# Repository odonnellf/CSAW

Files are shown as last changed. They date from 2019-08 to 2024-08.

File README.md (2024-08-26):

# CSAW
## (C)ontrol (S)urface using (A)rduino & (W)ireless capabilities

***This project is presented as part of the thesis requirements for the MSc. in Music & Technology, awarded by Cork School of Music.***

Audio control surfaces are practical tools for editing and mixing in a digital audio workstation. Despite recent technological advancements, however, there is a lack of robust physical commercial controllers with seamless wireless functionality.

This project repository consists of relevant files for the design and implementation of CSAW – an audio Control Surface built using the Arduino platform and Wireless capabilities. CSAW aims to remedy limitations of mobile control applications and certain hardware controllers through devising a proof of concept control surface and software platform using sophisticated open-source applications and wireless communication protocols.

## Software, Drivers & Libraries
(Installations covered in notes below)
* Arduino IDE
* Arduino Mega driver 
* ESP8266 board and library for Arduino IDE
* Purr Data - Pure Data distribution
* CNMAT/OSC Arduino library
* Arduino_Pd Pd abstraction library

## Repository Structure
/
* daw-files/	: DAW config files and templates for CSAW
* design/		: design diagrams and other documents
* documents/	: main thesis submission documents
* examples/	: example Arduino sketches and Pd patches, referenced in documentation
* main/		: main CSAW prototype Arduino sketches and Pd patches

## Install Notes
A Quick Start Guide accompanies this README with details on getting the controller working instantly (QuickStart.pdf). The steps below outline the process to replicate development, install requirements to enable code expansion on the controller and how to change the prototype build.

### I. Arduino:
	1. Download the Arduino IDE and install: https://www.arduino.cc/en/main/software .
	2. Connect CSAW's Arduino component via USB. Ensure that the correct board is selected in the IDE: Tools->Board->Arduino/Genuino Mega or Mega 2560
	3. Check that the correct port is selected under: Tools->Port. If this is greyed out, check that the Arduino is fully plugged in. If it is then there may be a driver issue, as Arduino Mega is known to have certain issues, particularly with Windows 10. Follow Arduino's documentation how to resolve this: https://www.arduino.cc/en/Guide/DriverInstallation 
	4. Prototype sketches and other code can now be uploaded to Arduino.

### II. ESP8266 (WiFi chip) board & library:
	1. To add the ESP8266 board manager and library, first go to: File->Preferences in the IDE.
	2. Paste the following link into the "Additional Boards Manager URLs" field and click OK: http://arduino.esp8266.com/stable/package_esp8266com_index.json
	3. Go to Tools->Board->Board Manager and search for 'ESP8266'. Select 'Install' and restart the IDE once it finishes.
	4. Sketches can now be uploaded to ESP8266 modules. Connect the module/device via USB.
	5. Select the appropriate board in the Tools->Board menu (for ESP-01 this is just 'Generic ESP8266 Module) and select the COM port.
	6. The library includes some examples to test the module works - e.g. Blink, etc.

### III. Open Sound Control library:
	1. Navigate to the main OSC GitHub repo for Arduino developed by CNMAT and download as a zip file: https://github.com/CNMAT/OSC .
	2. In the Arduino IDE, go to: Sketch->Include Library->Add .ZIP Library . Select the OSC zip and click OK.
	3. Once it finishes installing, restart the IDE. Under File->Examples, there should now be some extra examples under the OSC umbrella in the 'Examples from Custom Libraries' section.

### IV. Purr Data and abstractions
	1. CSAW uses the 'Purr Data' distribution of Pure Data. Download and install it from the GitHub repo at the following link: https://github.com/agraef/purr-data/releases .
	2. Download the 'Arduino_Pd' abstraction library: https://github.com/alexdrymonitis/Arduino_Pd .
	3. CSAW's Prototype A patch and examples use this library's 'serial_print.pd' patch for correctly reading values printed to Serial from Arduino. Copy this file into any directory with CSAW Pd code.

### V. CSAW:
	1. Download this project repository. Refer to the folder structure above for further details.
	2. Arduino and ESP sketches can now be easily uploaded via USB.
	3. Run the appropriate Prototype patch. For PrototypeA, select the USB COM port Arduino is connected to. For PrototypeB, wait for ESP to connect to Pd.
	4. Ensure that the patch is responding to controller actions.

### VI. DAW:
	(***For wireless/PrototypeB, connect to the network defined by the ESP8266 sketch and ensure the PC has the defined IP address.***)
	1. Open a supported DAW and import the config file. Alternatively, open the DAW template.
	2. This will contain all tracks, plugins/FX, OSC control surface etc. Double-check that the port matches the settings in the Prototype Pd patch. Import the REAPER key mapping file from the Action List menu.
	3. Check once more that actions are being mapped in the Prototype patch and then click the DAW connect button.

## System Requirements
- This system was developed and tested on a Dell Inspiron laptop with the following specifications:
	* Intel Core i7-8565U CPU @ 1.80GHz 1.99 GHz
	* 16.0GB installed memory (RAM)
	* Windows 10 Pro Operating System

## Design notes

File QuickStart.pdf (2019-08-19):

## CSAW Quick Start Guide

### Prototype B (Wireless) / DEFAULT

- CSAW is configured to send controller messages via its ESP8266 WiFi module over a LAN using the TP_Link router. To use another network/IP, refer to the documentation, as the PrototypeB_ESP.ino file will need to be updated with the new WiFi config & IP and then flashed to the chip.
1. Turn on the accompanying TP_Link Router and connect to it using the PC that will be running the
Pd software and DAW. | SSID: CSAW_router | Password: c5@w_123!
2. The router should automatically assign IP address 192.168.1.100 to the PC. If not, then login to the device with these credentials and assign it, as ESP is configured to forward messages to this IP.

Address: http://tplinkwifi.net/ Password: c5@w_123!

3. Power on CSAW’s Arduino component using the 12V power supply. It can also be powered using the battery pack or via USB (though the latter may be redundant for wireless comm).
4. Download Purr Data and install: https://github.com/agraef/purr-data/releases . Run ‘PrototypeB.pd’ and wait for the connection.
5. Patch faders/knobs may start moving sporadically on startup. These can be calibrated quickly by simply moving each knob/fader on the desk. It’s advised to do this before operating with the DAW.

IMPORTANT: On first startup, messages will stop coming in to Pure Data from ESP after about a minute. This occurs due to the high number of messages being sent from ESP as pot voltages change rapidly – assumed to occur due to built-up potential energy from the last time the controller was plugged out. Wait for the PrototypeB patch to start reacting to actions again and continuously move/calibrate pots, even when it comes back up. Be patient as this can sometimes take about 2-3 minutes. 99.9% of the time, after this fixes itself, everything will run smoothly without issue.

6. Once each sensor is (relatively) motionless, open the DAW and import the DAW config file. This will import the OSC control surface (double-check - listening on local port 9999), all tracks, plugins etc. Alternatively, open the DAW template directly. Import key mappings config from the Action List.
7. In the PrototypeB.pd patch, click the button to connect to the DAW. Controller operations should now interact with DAW functions.

### Prototype A (Wired)

- The wireless prototype (B) is flashed to CSAW’s Arduino by default so the ‘PrototypeA.ino’ sketch needs to be uploaded.
1. First, download and install the Arduino IDE: https://www.arduino.cc/en/main/software .
2. Open the PrototypeA.ino file in the IDE and connect the Arduino to the PC via USB.
3. Select the board type via Tools->Board->Arduino/Genuino Mega or Mega 2560.
4. Select the port via Port->COM port

NOTE: Arduino Mega is known to occasionally have issues with Windows, where the port section is greyed out so if this occurs download and reinstall the Mega driver (there is plenty of documentation online about this).

5. Upload the Arduino sketch.
6. Download Purr Data and the Arduino_Pd abstraction library from the GitHub repositories:
- https://github.com/agraef/purr-data/releases
- https://github.com/alexdrymonitis/Arduino_Pd .

Install Purr Data

7. Copy the ‘serial_print.pd’ from Arduino_Pd into the same directory as PrototypeA.pd.
8. Open PrototypeA.pd and select the COM port for Arduino
9. Again, patch faders/knobs will start moving on startup so calibrate manually (move each one).
10. Open the DAW and import the config file or open the template.
11. In the PrototypeA patch, click the button to connect to the DAW. Controller operations should now interact with DAW functions.

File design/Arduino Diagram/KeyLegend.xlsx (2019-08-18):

VCC | 5V voltage connections
GND | Ground connections
DATA | Arduino data inputs
MUX - C | MUX analog inputs connected to sensors
MUX - SIG / AN | MUX outputs / Arduino analog inputs
MUX - S0 | MUX Control Pin 0/A
MUX - S1 | MUX Control Pin 1/B
MUX - S2 | MUX Control Pin 2/C
TX/RX | Arduino TX serial to ESP8266 RX connection
RX/TX | Arduino RX serial to ESP8266 TX connection
POWER | Arduino battery power

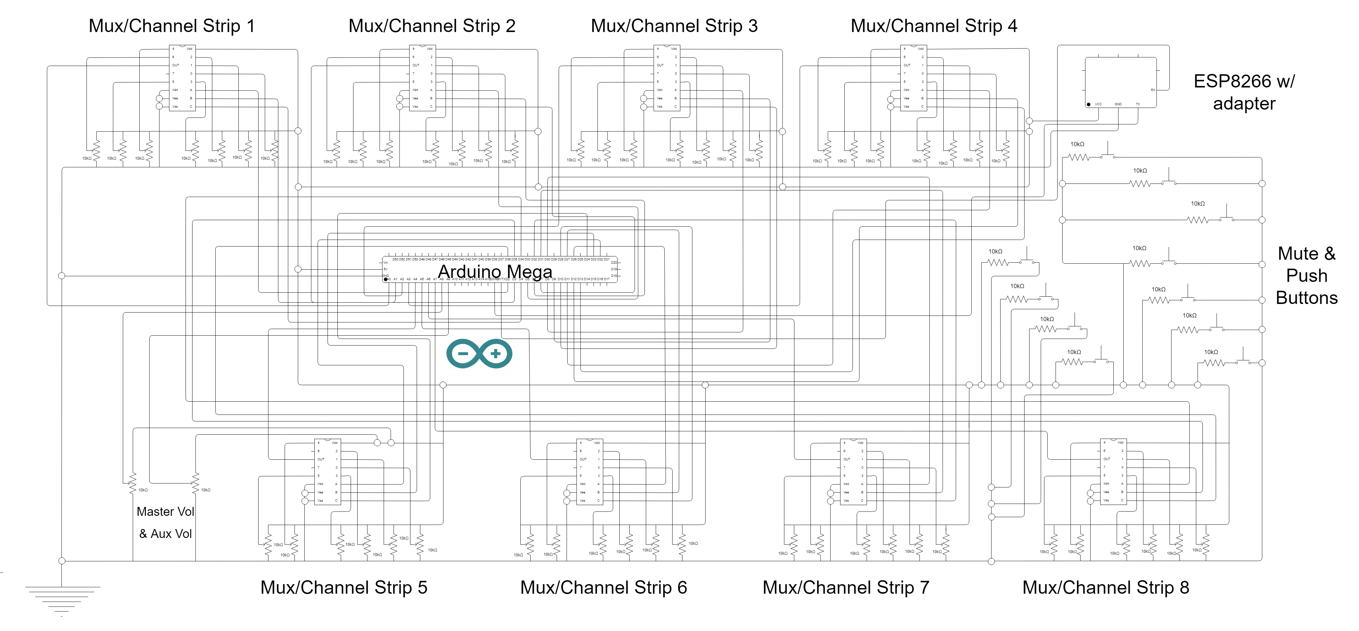
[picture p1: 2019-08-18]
design/Circuit Diagram/CircuitDiagram.png

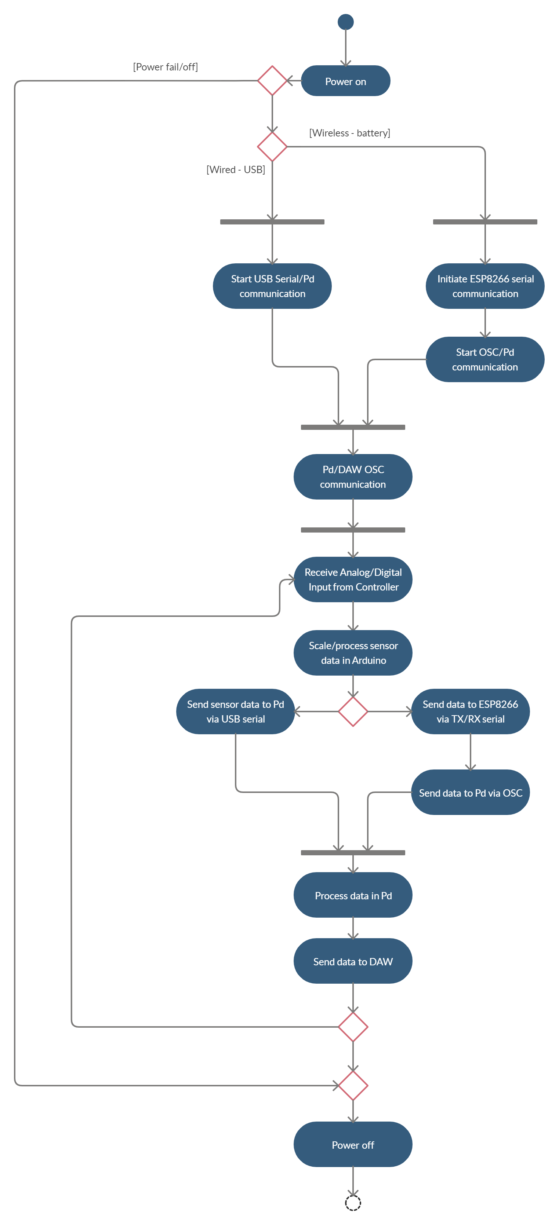
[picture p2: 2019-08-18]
design/Activity Diagram/ActivityDiagram.jpg

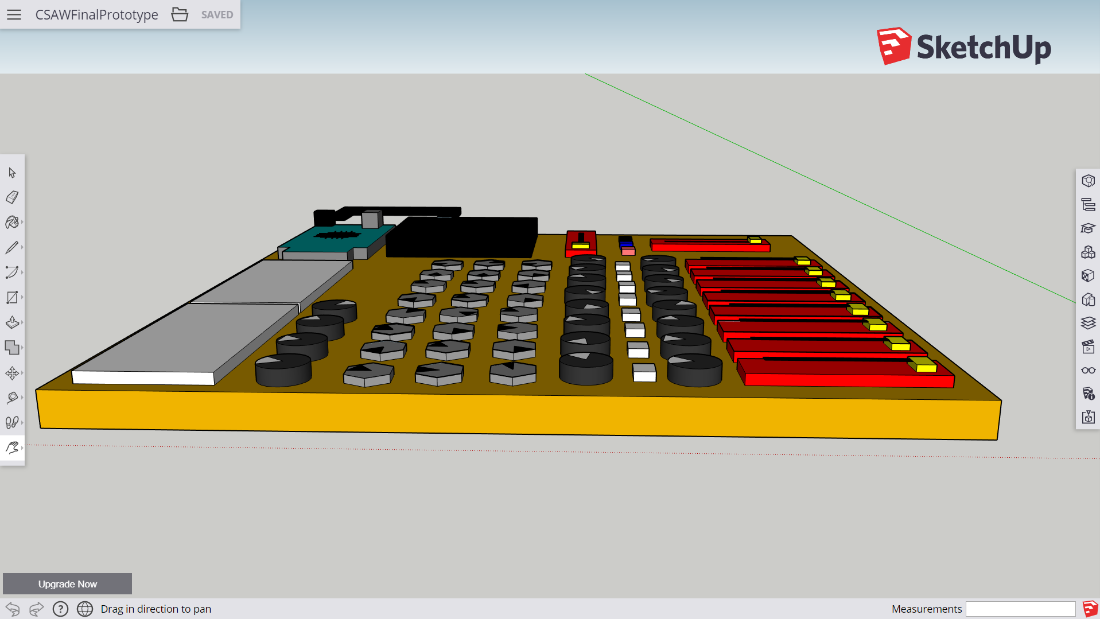
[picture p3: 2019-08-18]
design/SketchUp Render/CSAWFinalPrototype2.PNG

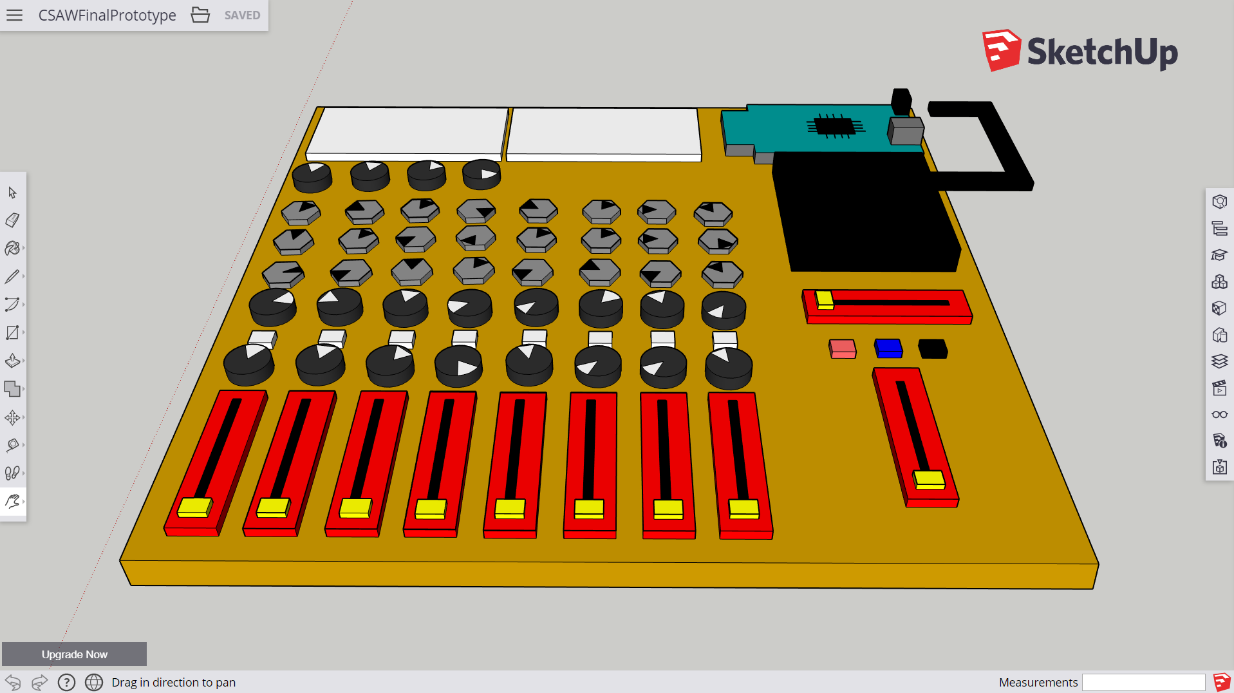
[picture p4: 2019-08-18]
design/SketchUp Render/CSAWFinalPrototype.PNG

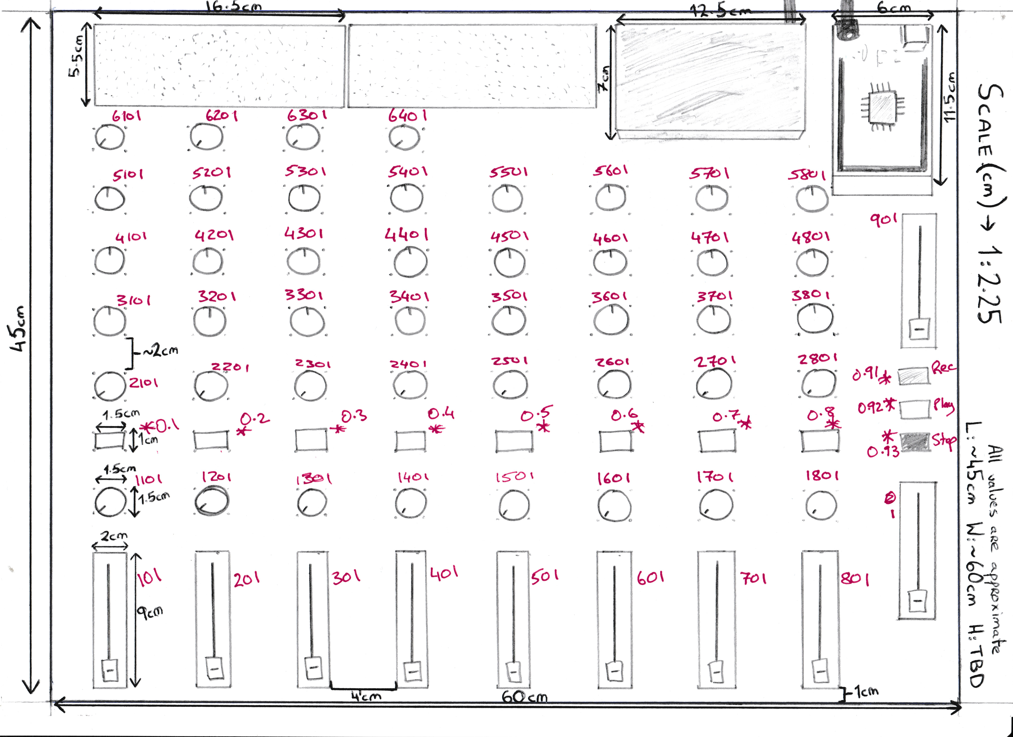
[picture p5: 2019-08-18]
design/Sketch & Numbering/sketch.jpg

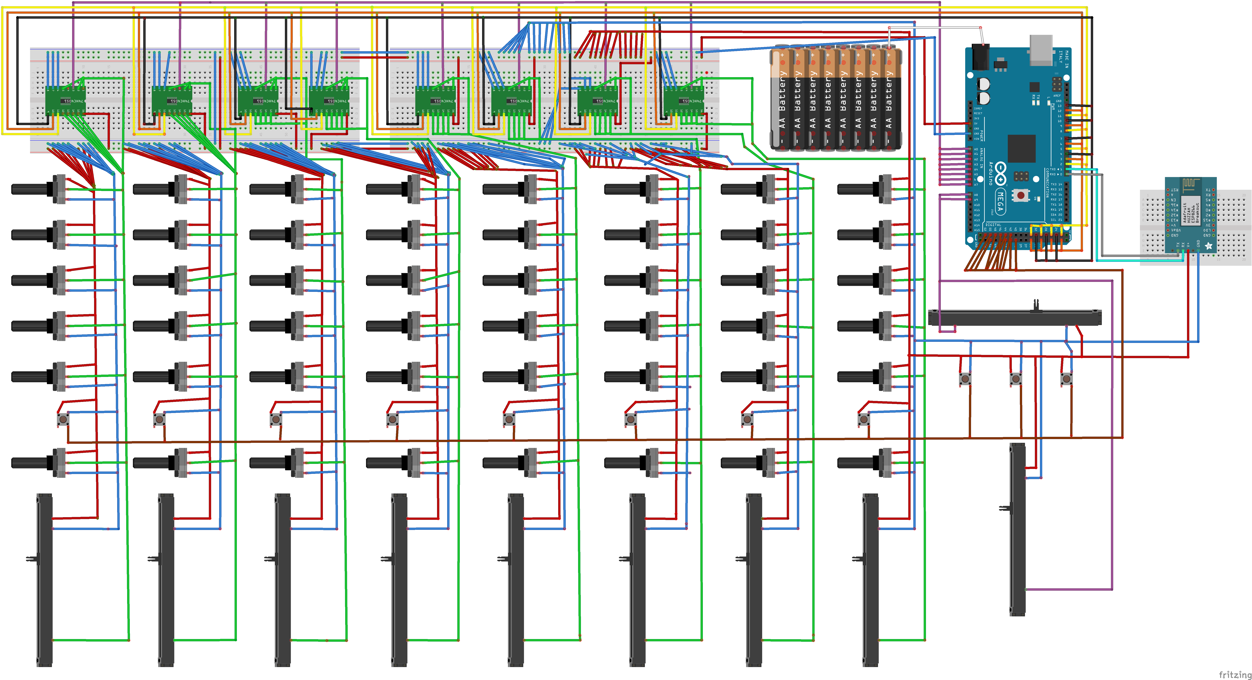
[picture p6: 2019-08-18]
design/Arduino Diagram/CSAWSketch.png

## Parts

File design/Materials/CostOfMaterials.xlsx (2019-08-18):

 |  |  |  | Items in red receommended, may not be required
 | Component | Quantity | Cost per unit | Comments
Arduino | Arduino Mega Rev3 | 1 | €35.00 | Purchased on arduino.cc - Arduino component for control surface | €35.00
 | Arduino Workshop Kit | 1 | €35.00 | Purchased on arduino.cc - includes mini breadboard, Arduino USB cable, additional small jumper wires & more | €35.00 | €70.00
Potentiometers & Buttons | 10k Slide Potentiometer set (5pcs) | 3 | €9.72 | Purchased on banggood.com - Double Analog Potentiometer Module With Slide Potentiometer | €29.16
 | YINNETECH 10k Rotary Potentiometer kit (20pcs) | 1 | €14.09 | Purchased on amazon.co.uk (vendor: E-NETTECH) | €14.09
 | Wimas 10k Rotary Potentiometer kit 45pcs | 1 | €18.99 | Purchased on amazon.co.uk (vendor: WiMas) | €18.99
 | Push Button set (50pk) | 1 | €4.34 | Purchased on amazon.co.uk (vendor: YoumileDirect) | €4.34 | €66.58
Jumper Wires | Jumper Wires set 30cm (150pcs) | 2 | €7.59 | Purchased on amazon.co.uk (vendor: MakerStack) | €15.18
 | Jumper Wires set 20cm (120pcs) | 2 | €5.37 | Purchased on amazon.co.uk (vendor: GanvolTech) | €10.74
 | Jumper Wires set 10cm (2 x 150pcs) | 1 | €6.50 | Purchased on amazon.co.uk (vendor: MakerStack) | €6.50 | €32.42
Breadboards | ELEGOO breadboard kit 830pt (3pcs) | 1 | €9.77 | Purchased on amazon.co.uk (vendor: GYE UK) | €9.77
 | ELEGOO breadboard kit 170pt (6pcs) | 1 | €6.50 | Purchased on amazon.co.uk (vendor: GYE UK) | €6.50
 | Electrely breadboard kit 170pcs (6pcs) | 2 | €6.16 | Purchased on amazon.co.uk (vendor: Electrely) | €12.32 | €28.59
Multiplexers | CD4051BE 8 channel mux (10pcs) | 2 | €6.04 | Purchased on amazon.co.uk (vendor: V&U Electronic Components Ltd) | €12.08 | €12.08
Wireless | Laqiya FT232RL USB TTL Converter (2pcs) | 1 | €9.23 | Purchased on amazon.co.uk (vendor: Laqiya) | €9.23
 | ESP-01 WiFi Module with breadboard adapter | 1 | €7.05 | Purchased on amazon.co.uk (vendor: AZ-Delivery-Shop) | €7.05
 | diymore ESP-01 Adapter Module | 1 | €6.51 | Purchased on amazon.co.uk (vendor: diymore) | €6.51
 | USB Mini B cable | 1 | €1.73 | Purchased on ebay.ie (vendor: bluechargedirect) | €1.73
 | ESP8266 NodeMCU dev board (2pcs) | 1 | €11.38 | Purchased on amazon.co.uk (vendor: amazon.co.uk EU S.a.r.L) | €11.38 | €35.90
Power & Misc. | MB102 Breadboard power supply adapter | 2 | €3.79 | Purchased on amazon.co.uk (vendor: Hengjiaan) - Haljia model | €7.58
 | 12V Battery Holder case | 1 | €6.51 | Purchased on amazon.co.uk (vendor: DIGISLIDER) - 8 x AA holder | €6.51
 | 12V power supply | 1 | €6.51 | Purchased on amazon.co.uk (vendor: LightingWill-UK) | €6.51
 | Ultrics Digital LCD Multimeter | 1 | €10.09 | Purchased on amazon.co.uk (vendor: ETHER UK) | €10.09
 | Resistor Assortment Kit (1280pcs) | 1 | €9.77 | Purchased on amazon.co.uk (vendor: Aussel) | €9.77
 | Aluminium Desk surface | 1 | N/A | Quote required, obtained for free | N/A | €40.46
 |  |  |  |  |  | €286.03

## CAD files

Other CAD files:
design/SketchUp Render/CSAWFinalPrototype.skp

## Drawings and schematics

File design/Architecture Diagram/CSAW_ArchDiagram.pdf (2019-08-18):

CSAW | PC

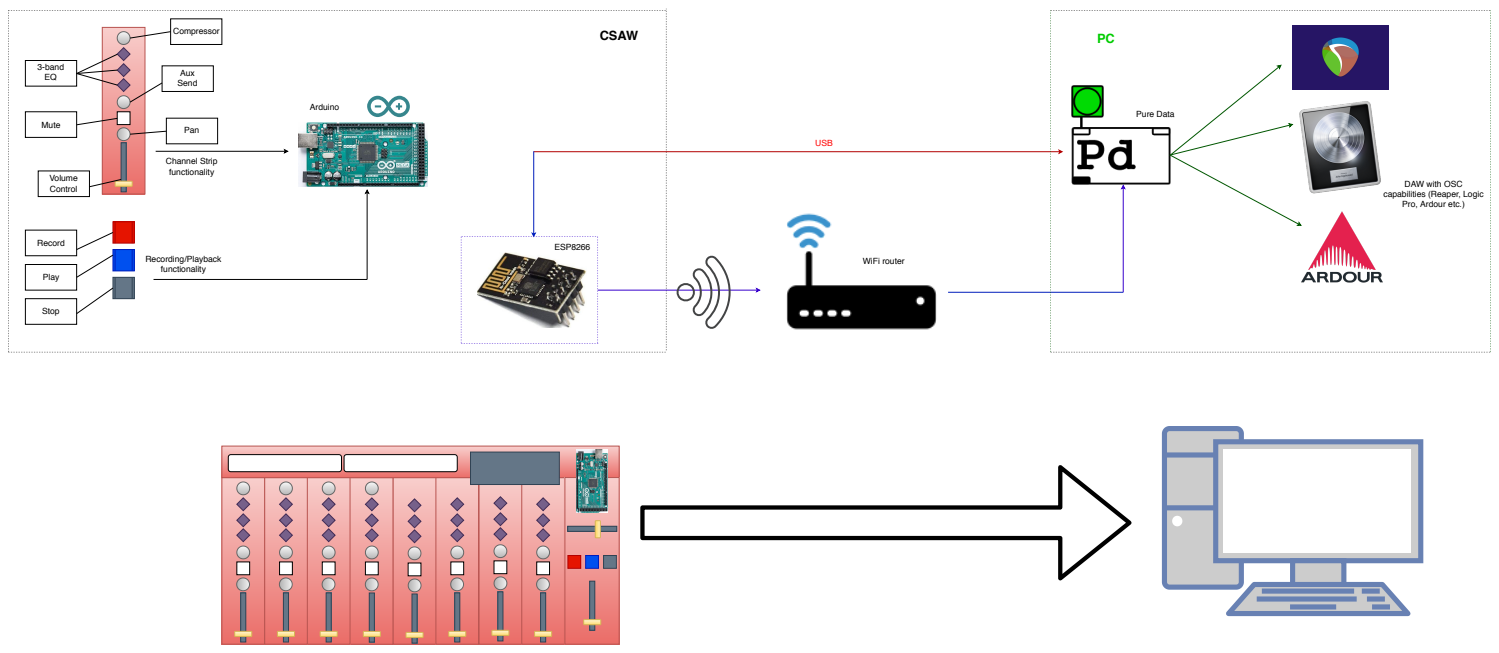
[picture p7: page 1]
Volume Control; Mute; Pan; 3-band EQ; Compressor; Aux Send; Record; Play; Stop; Recording/Playback functionality; Channel Strip functionality; Arduino; ESP8266; WiFi router; Pure Data; USB

DAW with OSC
capabilities (Reaper, Logic
Pro, Ardour etc.)

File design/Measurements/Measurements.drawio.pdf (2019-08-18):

# 2cm 60cm

12.5cm | 16.5cm

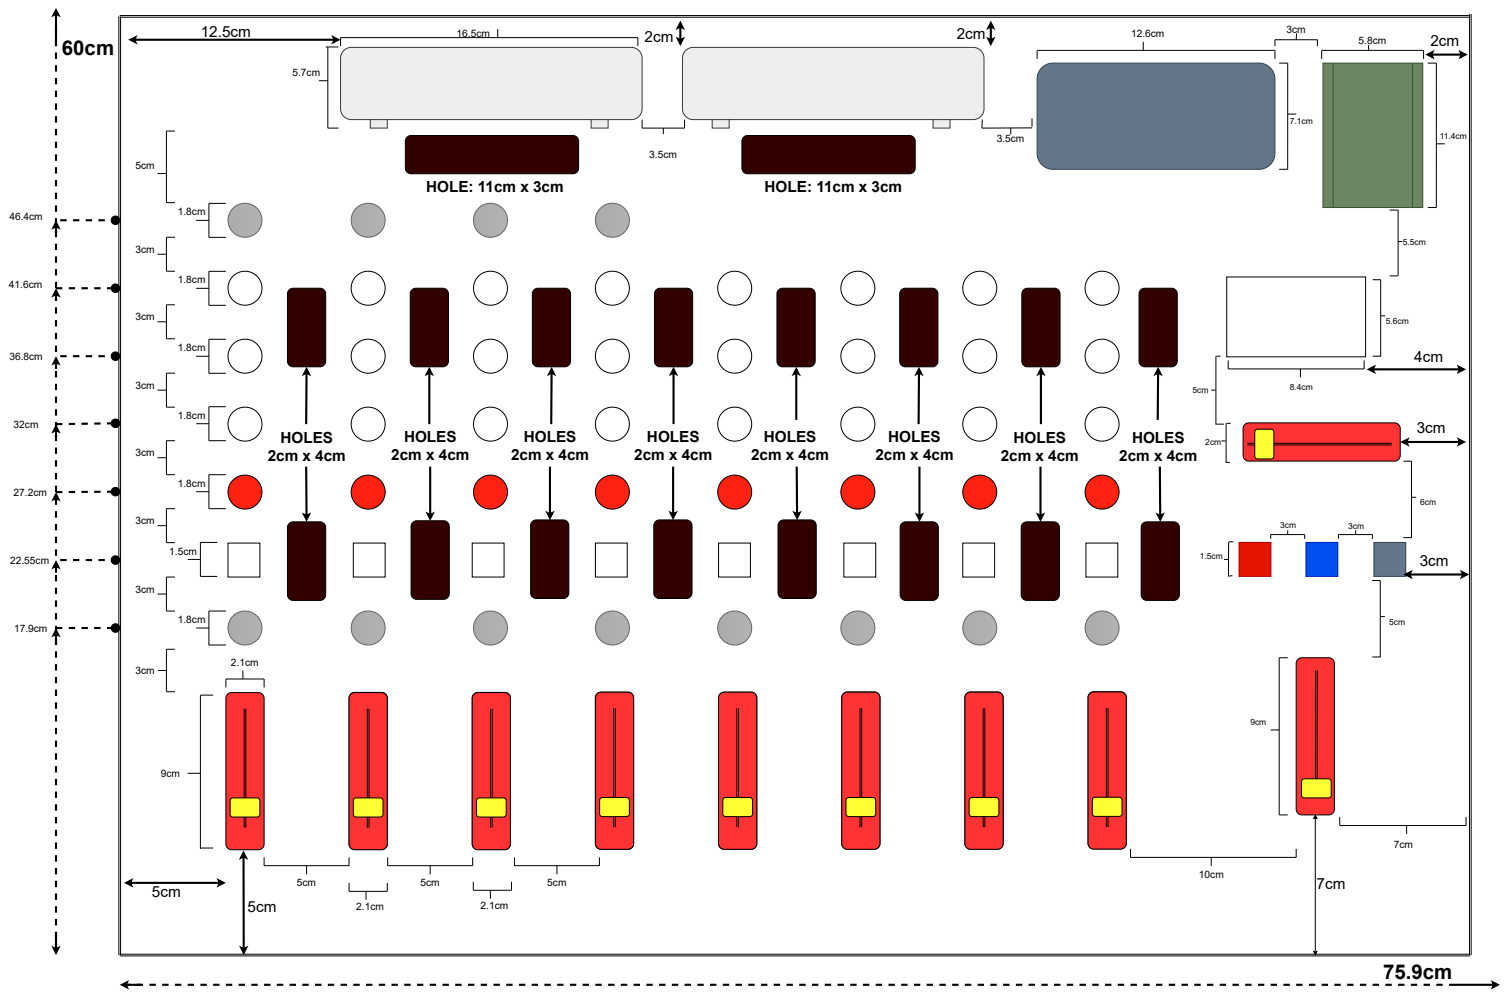
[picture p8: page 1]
HOLE: 11cm x 3cm; HOLES; HOLES 2cm x 4cm

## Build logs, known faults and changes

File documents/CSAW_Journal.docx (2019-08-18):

Fiach O’Donnell, C.I.T Cork School of Music

fiach.odonnell@mycit.ie

[^1]

# CSAW: An audio Control Surface built using the Arduino platform and Wireless capabilities

Abstract—Audio control surfaces are practical tools for editing and mixing in a digital audio workstation. Despite recent technological advancements, however, there is a lack of robust physical commercial controllers with seamless wireless functionality. This paper describes the design and implementation of CSAW – an audio Control Surface built using the Arduino platform and Wireless capabilities. CSAW aims to remedy limitations of mobile control applications and certain hardware controllers through devising a proof of concept control surface and software platform using sophisticated open-source applications and wireless communication protocols.

Index Terms—Arduino, control surface, OSC, Pd, ESP8266, wireless, DAW

# Nomenclature

CSAW Control Surface with Arduino Wireless capabilities

DAW Digital Audio Workstation

ESP ESP-01 ESP8266 WiFi Module

Pd Pure Data

OSC Open Sound Control

# I. Introduction

T

HE advent of smart phone technology and software applications in the modern age has undoubtably seen an increased interest in wireless and remote audio control within the audio production spectrum. The consolidation of music with the Internet of Things (IoT) in recent years has surpassed the expectations of engineers and enthusiasts alike, who continue to discover and implement new means of audio manipulation at a rapid rate.

Despite these advancements, however, there is still quite a lack of robust wireless capabilities for physical controllers/control surfaces on the market. Big name brands such as Behringer influence the pack with products like the X-Touch, but even so, this type of control is not as widely implemented as expected, considering the universal adoption of WiFi in the late 90s. For audio professionals, the necessity of a physical controller is imperative, given the frequent need to make multiple changes simultaneously, in contrast to the visual limitations and un-natural feel of changing parameters on the small screen.

The CSAW project aims to remedy this through utilising and consolidating existing technologies and hardware to construct a functional wireless physical control surface for audio manipulation. Through the use of sophisticated applications and communication protocols, along with a fundamental electronics environment with elemental components, a proof of concept controller and software platform will be devised to enable the audio engineer to perform mixing and recording functions in an easier, more efficient manner than its software counterparts.

# II. Background & Design

An audio control surface refers to a device or interface that “allows the user to control a digital audio workstation or other digital audio application” [1]. These range from the primitive, such as Behringer’s X-Touch Mini [2] with its single fader and 8 rotary potentiometers for track volume control, to the more elaborate, like Avid’s Pro Tools S3 [3], which allows for a wider range of functionality such as automation, routing management, etc. CSAW acts as such an interface, allowing for basic DAW and track control implemented through Arduino and WiFi capabilities.

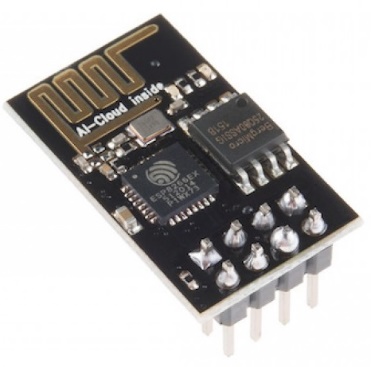
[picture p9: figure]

Fig. 1. ESP-01: ESP8266 WiFi module

At its core, CSAW design is closer to a combination of control surface and analog console than to a typical control surface. The controller includes analog sensors with pre-mapped controls for the more common DAW functions. It also makes use of DAW built-in OSC capabilities instead of sluggish WiFi setup and configuration over some of its counterparts.

CSAW houses a WiFi transceiver, the ESP-01 (Fig.1) [4], a model of the ESP8266 module to provide easier connectivity for the core Arduino component to a pre-existing network. Making use of simple, affordable electronic potentiometers and push buttons that connect to the Arduino Mega [5], the CSAW control surface keeps to a compact design. Layout is based on the Behringer Xenyx X1222USB analog mixer [6].

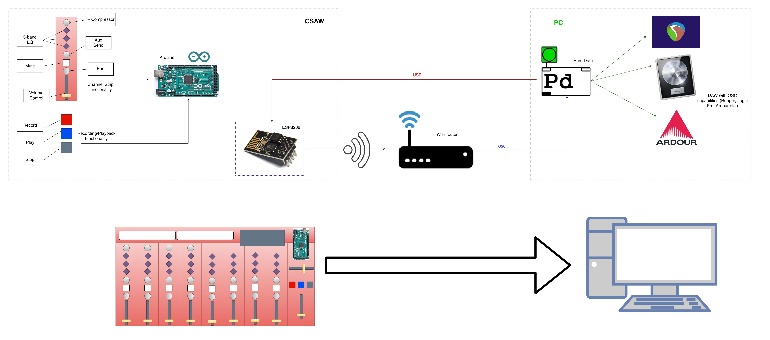
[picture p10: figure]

The Pure Data [7] visual programming language is utilised as middleware software, collecting sensor messages from the controller Arduino component and processing and broadcasting them to a DAW. These messages are communicated via Open Sound Control [8] – a message-based protocol for communication among computers, sound synthesizers and other multimedia devices and applications that is optimized for network distributed music systems. OSC was selected over the likes of MIDI based on its user-defined message structure and robust ability to define different data types among others.

Fig. 2. CSAW architecture

# III. IMPLEMENTATION

Two separate communication methods were used to send audio control to a DAW on a computer; a) transmitting control signals via USB (wired connection) or b) via WiFi using the ESP8266 chip (Fig.2). The Arduino Mega component scaled analog/digital data read from the controller’s potentiometers and pushbuttons before sending them via serial to either USB or ESP. The numerical data was then received on a local instance of Pd running on the DAW PC through either method - the latter utilising OSC for ESP->Pd transmission. Both methods then utilised Pd to configure separate OSC messages to map data to built-in DAW actions, performing the appropriate task (e.g. volume control, equalization, etc.).

All potentiometers and resistors used were of 10kΩ resistance – the optimum value as anything smaller consumes current while anything larger takes longer to read or can be affected by values of other pots. Multiplexers were employed to extend analog inputs due to limitations of Arduino. The project applied 8xCD4051BE 8-channel muxes, developed by Texas Instruments Inc., to route sensor inputs for each channel strip to Arduino’s analog pins.

CSAW makes use of contributions from the GitHub community for streamlining controller operations. The two primary repositories that were invoked during implementation were ‘Arduino_Pd’ – a library of Pd abstractions for facilitating reading of serial data [9] – and the main OSC library developed at CNMAT for Arduino integration [10].

Desk construction was outsourced to a local sign and display solutions company, given a measurements diagram (Fig.3). Basic black-box user testing comprised querying statements to testers based on John Brooke’s System Usability Scale [11], for measuring the system’s usability.

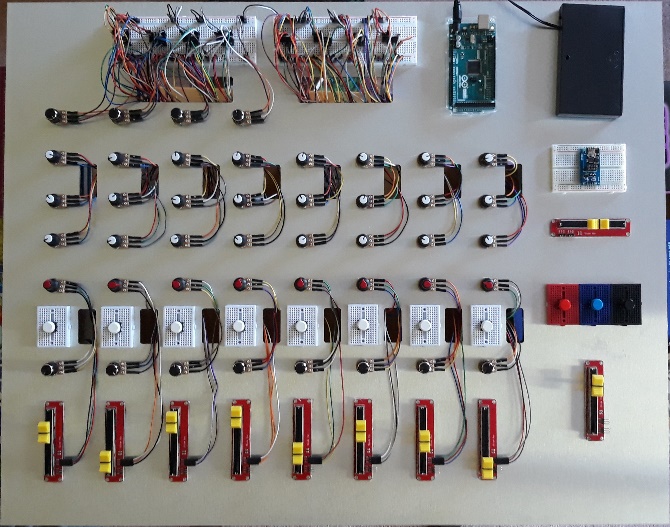
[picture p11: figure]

Fig. 3. CSAW final prototype

# IV. Conclusion

The CSAW audio control surface successfully amounts to the principal capabilities of a DAW controller, proving itself among the many software-centric systems that currently dominate the market. With its recognisable design and built-in WiFi transceiver for consistent wireless facilities, CSAW exhibits an ergonomic digital workstation controller for the modern audio engineer, providing a key functionality that’s ignored by many wholesale controllers.

Through its use of exclusively fundamental electronics and strictly open-source technologies and platforms, CSAW proves competent in matching many of the commercial physical products available in the public domain at present.

# V. Acknowledgements

This work was presented as part of the requirements for the MSc. in Music & Technology, awarded by C.I.T Cork School of Music (CSM). The author would like to thank Hugh McCarthy & Paddy Collins among other CSM lecturers, along with course colleagues and the author’s parents.

# VI. References

[1] Wikipedia contributors. Audio control surface. In Wikipedia, The Free Encyclopedia. Retrieved 12:01, August 12, 2019, from https://en.wikipedia.org/w/index.php?title=Audio_control_surface&oldid=827929386
[2] Behringer. (2014). X-TOUCH MINI: Quick Start Guide.
[3] Avid. (2014). Pro Tools | S3 User Guide.
[4] AI-Thinker. (2015). ESP-01 WiFi Module Version 1.0.
[5] Arduino Mega. (2019) arduino.cc: https://store.arduino.cc/mega-2560-r3
[6] Behringer. (2019). Xenyx X1222USB User Manual.
[7] Puckette, M. S. (2016). Pure Data.
[8] Wright, M., Freed, A., & CNMAT. (1997). Open Sound Control: A New Protocol for Communicating with Sound Synthesizers.
[9] alexdrymonitis/Arduino_Pd. Retrieved from GitHub.com: https://github.com/alexdrymonitis/Arduino_Pd
[10] CNMAT/OSC. Retrieved from GitHub.com: https://github.com/CNMAT/OSC
[11] Brooke, J. (1986). SUS - A quick and dirty usability scale.

[^1] . F. O’Donnell is with C.I.T Cork School of Music, Union Quay, Ballintemple, Cork, Ireland (e-mail: fiach.odonnell@mycit.ie).

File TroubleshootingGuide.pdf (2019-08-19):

## CSAW Troubleshooting Guide

- CSAW’s Pure Data Prototype patches have GUIs matching the controller layout with faders, knobs and buttons that reacts to controller mappings. For this reason, they can be useful for troubleshooting, so it’s advised to open the relevant Prototype patch and check to see if this is responding to the controller before reading on.

### PrototypeB Scenarios

The DAW session is not responding to controller functions.

- Open the PrototypeB.pd patch; is this responding to controller functions? If no, refer to the scenario below. If yes, then the issue is with how Pd is communicating with the DAW.
- Click the button on the PrototypeB.pd patch GUI to re-connect to the DAW and wait a minute. Did this work?
- Does the OSC control surface match the settings/port of the patch? Is there an OSC control surface in the DAW settings? Check the port number and IP.
- Has the key mappings file been imported?
- If the settings match and there’s no broken Pd connection links, restart the PrototypeB patch and reupload the DAW config or open the template from the USB/project GitHub repo (https://github.com/odonnellf/CSAW/).

The PrototypeB.pd GUI is not responding to controller functions.

IMPORTANT: On first startup, messages will stop coming in to Pure Data from ESP after about a minute. This occurs due to the high number of messages being sent from ESP as pot voltages change rapidly – assumed to occur due to built-up potential energy from the last time the controller was plugged out. Wait for the PrototypeB patch to start reacting to actions again and continuously move/calibrate pots, even when it comes back up. Be patient as this can sometimes take about 2-3 minutes. 99.9% of the time, after this fixes itself, everything will run smoothly without issue.

- Double-click the ‘main’ patch in the top-right corner of PrototypeB.pd to open. Did this kickstart numerical values to start coming in to the various number boxes and is the patch responding?
- If not, then the OSC messages from ESP are not being received by Pure Data. This can be for a number of reasons:
- Is the PC that is running the DAW/Pd connected to the appropriate network? Does it have the correct IP per the Quick Start Guide?
- Are the ESP pins connected properly to Arduino? By default, RX and TX from the ESP-01 adapter are connected to pins 15 and 14. VCC and GND are connected to the smaller breadboard’s VCC and GND rails.

- Upload the PrototypeA.ino file to Arduino and open the PrototypeA.pd patch on the appropriate COM port via USB. If the PrototypeA.pd GUI responds to controller functions after selectin the COM port, then there is nothing wrong with Arduino/sensor connections and the issue is with either ESP or Pure Data.
- Has the Arduino or ESP code been altered in any way? Re-upload the correct Prototype patch and ESP code from the USB or project GitHub repository. Section 4.2.1 outlines ESP code upload.

### PrototypeA Scenarios

The PrototypeA.pd GUI is not responding to controller functions.

- Has the PrototypeA.ino Arduino sketch been uploaded to Arduino via USB? Similarly, ensure that Arduino is being powered over USB instead of DC/battery as PrototypeA’s serial communication works over USB.
- Has the relevant USB COM port been selected in the PrototypeA patch? Check that Arduino is running and that all its pin-breadboard connections aren’t loose.

### Other

A specific pot/fader is not working in the DAW/Prototype patch.

- Open the Prototype patch and move the sensor. Is It responding in the patch? If yes, then there is a problem with how the message is being sent to the DAW or the mapping in the DAW is incorrect. All messages for CSAW were mapped appropriately so (assuming these have been edited), re-download the Prototype patch and re-upload the DAW config or open the template on the USB/repo.
- Are the jumper wires connected to the pot loose/separating from the pin connection? Some connections can come loose easier than others, especially when moving to a new surface, so ensure these are fit snugly.
- If the issue persists then there are a few potential reasons:
1. Loose or damaged jumper wires – some wires are daisy-chained from sensors. While they were solidly stuck together it’s possible that they may have become damaged or have come loose so double-check this.
2. Similarly, there could be a loose breadboard connection. Follow the wires to the breadboard, ensuring that the two outside rotary pot pins are connected comfortably to VCC and GND rails on the breadboard (doesn’t matter which as long as both are covered) and the middle pin connects to a pin next to one of the multiplexers (one of the 8 black circuit-boards that line the breadboards). For slide pots, DTB is the multiplexer connection and VCC/GND are labelled appropriately.
3. The multiplexer pin connection could be faulty. Unfortunately, there’s nothing to do here outside of ensuring the multiplexer pins fit fully into the breadboard.

Nothing is working at all!

- Is the Arduino component plugged in/are there LEDs indicating that the device is on? Similarly, if using wireless communication, is the red LED on the WiFi chip on? If not, check appropriate power/pin connections.
- Assuming it’s powered on, it’s unlikely that at least a few controls wouldn’t be working correctly. If this is the case, check that the 5V and GND pins on Arduino are connected to the breadboard via the small red and blue jumper wires. Then check that all the analog and digital pin connections are correct and fit comfortably.

Note: The main document has a table of all pin connections in the Appendix C.11.

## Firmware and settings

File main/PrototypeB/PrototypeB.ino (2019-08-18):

/***PrototypeB***/
// Main Arduino Prototype B sketch for CSAW controller, using CD4051BE muxes
// Scales all pot values and responds to push buttons, printing to serial bus with ESP8266

// SoftwareSerial library included with Arduino IDE
#include <SoftwareSerial.h>
SoftwareSerial s(15, 14); // Arduino RX pin is 15, TX is 14

// Initialise values for each analog input and old values to compare with later before sending
// (if new value is 1 above or 1 below old value - i.e. regular pot jitter - then it won't be sent)
int input1Values[7], input1OldValues[7];
int input2Values[7], input2OldValues[7];
int input3Values[7], input3OldValues[7];
int input4Values[7], input4OldValues[7];
int input5Values[7], input5OldValues[7];
int input6Values[7], input6OldValues[7];
int input7Values[7], input7OldValues[7];
int input8Values[7], input8OldValues[7];
int masterVol, masterOldVol;
int sendVol, sendOldVol;

// Initialise all mux pins
const int mux1Pins[3] = {2, 3, 4}; // S0=2, S1=3, S2=4
const int mux2Pins[3] = {5, 6, 7}; // etc.
const int mux3Pins[3] = {8, 9, 10};
const int mux4Pins[3] = {11, 12, 13};
const int mux5Pins[3] = {22, 23, 24};
const int mux6Pins[3] = {26, 27, 28};
const int mux7Pins[3] = {30, 31, 32};
const int mux8Pins[3] = {34, 35, 36};

// Mux connections to Arduino analog inputs
const int mux1Input = A1; // Connect common OUT of Mux 1 to A1 (A0 is master vol and A9 is send vol)
const int mux2Input = A2; // etc.
const int mux3Input = A3;
const int mux4Input = A4;
const int mux5Input = A5;
const int mux6Input = A6;
const int mux7Input = A7;
const int mux8Input = A8;

// Button pin connections and state variables/previous reading/current reading
int mute1PIN = 41, state1 = LOW, previous1 = HIGH, reading1;
int mute2PIN = 42, state2 = LOW, previous2 = HIGH, reading2;
int mute3PIN = 43, state3 = LOW, previous3 = HIGH, reading3;
int mute4PIN = 44, state4 = LOW, previous4 = HIGH, reading4;
int mute5PIN = 45, state5 = LOW, previous5 = HIGH, reading5;
int mute6PIN = 46, state6 = LOW, previous6 = HIGH, reading6;
int mute7PIN = 47, state7 = LOW, previous7 = HIGH, reading7;
int mute8PIN = 48, state8 = LOW, previous8 = HIGH, reading8;
int recPIN = 50, stateR = LOW, previousR = HIGH, readingR;
int playPIN = 51, stateP = LOW, previousP = HIGH, readingP;
int stopPIN = 52, stateS = LOW, previousS = HIGH, readingS;

// Starting variable for pot ranges and debouncing variables for push buttons
int start = 101;
long time = 0, debounce = 200;

void setup() 
{
  // Initialize the serial port with baud rate of 115200 bits per second
  s.begin(115200);
  
  // Set up the mux pins as outputs and write HIGH to each  to initialise
  for (int i=0; i<3; i++)
  {
    pinMode(mux1Pins[i], OUTPUT);
    pinMode(mux2Pins[i], OUTPUT);
    pinMode(mux3Pins[i], OUTPUT);
    pinMode(mux4Pins[i], OUTPUT);
    pinMode(mux5Pins[i], OUTPUT);
    pinMode(mux6Pins[i], OUTPUT);
    pinMode(mux7Pins[i], OUTPUT);
    pinMode(mux8Pins[i], OUTPUT);
    digitalWrite(mux1Pins[i], HIGH);
    digitalWrite(mux2Pins[i], HIGH);
    digitalWrite(mux3Pins[i], HIGH);
    digitalWrite(mux4Pins[i], HIGH);
    digitalWrite(mux5Pins[i], HIGH);
    digitalWrite(mux6Pins[i], HIGH);
    digitalWrite(mux7Pins[i], HIGH);
    digitalWrite(mux8Pins[i], HIGH);
  }

  // Set up all analog pins to read inputs
  pinMode(mux1Input, INPUT);
  pinMode(mux2Input, INPUT);
  pinMode(mux3Input, INPUT);
  pinMode(mux4Input, INPUT);
  pinMode(mux5Input, INPUT);
  pinMode(mux6Input, INPUT);
  pinMode(mux7Input, INPUT);
  pinMode(mux8Input, INPUT);

  // Set up all digital push button pins to read inputs
  pinMode(mute1PIN, INPUT);
  pinMode(mute2PIN, INPUT);
  pinMode(mute3PIN, INPUT);
  pinMode(mute4PIN, INPUT);
  pinMode(mute5PIN, INPUT);
  pinMode(mute6PIN, INPUT);
  pinMode(mute7PIN, INPUT);
  pinMode(mute8PIN, INPUT);
  pinMode(recPIN, INPUT);
  pinMode(playPIN, INPUT);
  pinMode(stopPIN, INPUT);
}

void loop() 
{
  //***POTENTIOMETERS***//
  
  // Loop through first seven of the eight mux pins
  for (byte pin=0; pin<=6; pin++)
  {
    selectMuxPin(mux1Pins, pin); // Select one at a time
    input1Values[pin] = analogRead(mux1Input); // Read OUT
    input1Values[pin] = map(input1Values[pin], 0, 1023, start, start+99); // Scale it to range
    if(input1Values[pin] < (input1OldValues[pin]-1) || input1Values[pin] > (input1OldValues[pin]+1)) { // if new pot value is more than 1 above or 1 below last value
      s.println(input1Values[pin]); // Print to serial
      input1OldValues[pin] = input1Values[pin]; // Set old value to equal current value for next loop
    }

    selectMuxPin(mux2Pins, pin);
    input2Values[pin] = analogRead(mux2Input);
    input2Values[pin] = map(input2Values[pin], 0, 1023, start+100, start+199);
    if(input2Values[pin] < (input2OldValues[pin]-1) || input2Values[pin] > (input2OldValues[pin]+1)) {
      s.println(input2Values[pin]);
      input2OldValues[pin] = input2Values[pin];
    }

    selectMuxPin(mux3Pins, pin);
    input3Values[pin] = analogRead(mux3Input);
    input3Values[pin] = map(input3Values[pin], 0, 1023, start+200, start+299);
    if(input3Values[pin] < (input3OldValues[pin]-1) || input3Values[pin] > (input3OldValues[pin]+1)) {
      s.println(input3Values[pin]);
      input3OldValues[pin] = input3Values[pin];
    }

    selectMuxPin(mux4Pins, pin);
    input4Values[pin] = analogRead(mux4Input);
    input4Values[pin] = map(input4Values[pin], 0, 1023, start+300, start+399);
    if(input4Values[pin] < (input4OldValues[pin]-1) || input4Values[pin] > (input4OldValues[pin]+1)) {
      s.println(input4Values[pin]);
      input4OldValues[pin] = input4Values[pin];
    }
       
    selectMuxPin(mux5Pins, pin);
    input5Values[pin] = analogRead(mux5Input);
    input5Values[pin] = map(input5Values[pin], 0, 1023, start+400, start+499);
    if(input5Values[pin] < (input5OldValues[pin]-1) || input5Values[pin] > (input5OldValues[pin]+1)) {
      s.println(input5Values[pin]);
      input5OldValues[pin] = input5Values[pin];
    }

    selectMuxPin(mux6Pins, pin);
    input6Values[pin] = analogRead(mux6Input);
    input6Values[pin] = map(input6Values[pin], 0, 1023, start+500, start+599);
    if(input6Values[pin] < (input6OldValues[pin]-1) || input6Values[pin] > (input6OldValues[pin]+1)) {
      s.println(input6Values[pin]);
      input6OldValues[pin] = input6Values[pin];
    }

    selectMuxPin(mux7Pins, pin);
    input7Values[pin] = analogRead(mux7Input);
    input7Values[pin] = map(input7Values[pin], 0, 1023, start+600, start+699);
    if(input7Values[pin] < (input7OldValues[pin]-1) || input7Values[pin] > (input7OldValues[pin]+1)) {
      s.println(input7Values[pin]);
      input7OldValues[pin] = input7Values[pin];
    }

    selectMuxPin(mux8Pins, pin);
    input8Values[pin] = analogRead(mux8Input);
    input8Values[pin] = map(input8Values[pin], 0, 1023, start+700, start+799);
    if(input8Values[pin] < (input8OldValues[pin]-1) || input8Values[pin] > (input8OldValues[pin]+1)) {
      s.println(input8Values[pin]);
      input8OldValues[pin] = input8Values[pin];
    }
    
    start = start+1000; // Increment start variable by 1000 for next channel 'row' (Row1 = volume, row2 = panning, etc.)
  }

  //***PUSH BUTTONS***//

  // Read pin, change state based on previous value and debounce
  // Set new time variable and set new previous value to current pin reading
  reading1 = digitalRead(mute1PIN);
  if (reading1 == LOW && previous1 == HIGH && millis() - time > debounce) { s.println(9991); time = millis(); }
  previous1 = reading1;

  reading2 = digitalRead(mute2PIN);
  if (reading2 == LOW && previous2 == HIGH && millis() - time > debounce) { s.println(9992); time = millis(); }
  previous2 = reading2;

  reading3 = digitalRead(mute3PIN);
  if (reading3 == LOW && previous3 == HIGH && millis() - time > debounce) { s.println(9993); time = millis(); }
  previous3 = reading3;

  reading4 = digitalRead(mute4PIN);
  if (reading4 == LOW && previous4 == HIGH && millis() - time > debounce) { s.println(9994); time = millis(); }
  previous4 = reading4;

  reading5 = digitalRead(mute5PIN);
  if (reading5 == LOW && previous5 == HIGH && millis() - time > debounce) { s.println(9995); time = millis(); }
  previous5 = reading5;

  reading6 = digitalRead(mute6PIN);
  if (reading6 == LOW && previous6 == HIGH && millis() - time > debounce) { s.println(9996); time = millis(); }
  previous6 = reading6;

  reading7 = digitalRead(mute7PIN);
  if (reading7 == LOW && previous7 == HIGH && millis() - time > debounce) { s.println(9997); time = millis(); }
  previous7 = reading7;

  reading8 = digitalRead(mute8PIN);
  if (reading8 == LOW && previous8 == HIGH && millis() - time > debounce) { s.println(9998); time = millis(); }
  previous8 = reading8;

  readingR = digitalRead(recPIN);
  if (readingR == LOW && previousR == HIGH && millis() - time > debounce) { s.println(99991); time = millis(); }
  previousR = readingR;

  readingP = digitalRead(playPIN);
  if (readingP == LOW && previousP == HIGH && millis() - time > debounce) { s.println(99992); time = millis(); }
  previousP = readingP;

  readingS = digitalRead(stopPIN);
  if (readingS == LOW && previousS == HIGH && millis() - time > debounce) { s.println(99993); time = millis(); }
  previousS = readingS;

  //***MASTER AND SEND VOLUMES***//
  masterVol = analogRead(A0); // Read OUT
  masterVol = map(masterVol, 0, 1023, 1, 100); // Scale it to range
  if(masterVol < (masterOldVol-1) || masterVol > (masterOldVol+1)){ // same check against old value
    s.println(masterVol);
    masterOldVol = masterVol;
  }
  
  sendVol = analogRead(A9);
  sendVol = map(sendVol, 0, 1023, 901, 1000);
  if(sendVol < (sendOldVol-1) || sendVol > (sendOldVol+1)){
    s.println(sendVol);
    sendOldVol = sendVol;
  }
    
  delay(100); // delay based on noticeable latency to humans, >100ms is noticeable, could potentially be scaled back but is a safe value
  start = 101; // reset start value before running through muxes again
}

// Function sets the S0, S1, and S2 pins, given a mux pin from 0 to 7
// writes HIGH and LOW to select pins for each input
void selectMuxPin(int muxPins[], byte pin)
{
  for (int i=0; i<3; i++)
  {
    if (pin & (1<<i))
      digitalWrite(muxPins[i], HIGH);
    else
      digitalWrite(muxPins[i], LOW);
  }
}

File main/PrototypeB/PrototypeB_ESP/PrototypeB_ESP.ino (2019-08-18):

/***PrototypeB_ESP***/
// Main ESP code for Prototype B - reads serial values from Arduino and sends to Pd over WiFi
// WiFi settings set to CSAW_router by default, if changing to other network make sure to change computer IP too
// Adapted from CNMAT OSC ESP8266 Send Message example: https://github.com/CNMAT/OSC/blob/master/examples/ESP8266sendMessage/ESP8266sendMessage.ino

// Include ESP8266 and OSC libraries
// For details on installing, refer to CSAW README file
#if defined(ESP8266)
#include <ESP8266WiFi.h>
#else
#include <WiFi.h>
#endif
#include <WiFiUdp.h>
#include <OSCMessage.h>

// TP_Link router
char ssid[] = "CSAW_router";// your network SSID (name)
char pass[] = "c5@w_123!";  // your network password

WiFiUDP Udp; // UDP instance to send and receive packets over UDP
const IPAddress outIp(192,168,1,100);// remote IP of PC running Pd and DAW
const unsigned int outPort = 8888; // remote port to receive OSC
const unsigned int localPort = 9999; // local port to listen for OSC packets (actually not used for sending)

// Initialise variables to contain value read from Serial, last Serial value and placeholder string when reading from Serial
int val;
int lastVal;
String placeString = "";


void setup() {
    Serial.begin(115200); // baud rate - 1115200 is typical for ESP

    // Connect to WiFi network
    Serial.println();
    Serial.println();
    Serial.print("Connecting to ");
    Serial.println(ssid);
    WiFi.begin(ssid, pass);

    // Continuously try connecting to network
    while (WiFi.status() != WL_CONNECTED) {
        delay(500);
        Serial.print(".");
    }
    Serial.println("");

    Serial.println("WiFi connected");
    Serial.println("IP address: ");
    Serial.println(WiFi.localIP());

    Serial.println("Starting UDP");
    Udp.begin(localPort);
    Serial.print("Local port: ");
#ifdef ESP32
    Serial.println(localPort);
#else
    Serial.println(Udp.localPort());
#endif
    
    while (!Serial) {
    ; // wait for serial port to connect. Needed for USB port only
  }
}

void loop() {
  // if there is a value available from the Serial bus
  if (Serial.available()) {
      // Read in the serial data to var serialChar
      int serialChar = Serial.read();
      if (isDigit(serialChar)) {
        // saved incoming data is a byte so convert this to a char and add it to placeholder string
        placeString += (char)serialChar;
      }
      // if you get a newline (i.e for each new value)
      if (serialChar == '\n') {
        // convert the placeholder string, it's now an integer!
        val = placeString.toInt();

        // The if statement after this ones ensures that repeat values aren't sent, however we don't want this to happen for push buttons (will always be same value!)
        // This if statement checks if the value is a push button value and if it is, send the message every time
        if( val == 9991 || val == 9992 || val == 9993 || val == 9994 || val == 9995 || val == 9996 || val == 9997 || val == 9998 || val == 99991 || val == 99992 || val == 99993){
            OSCMessage msg("/esp");
            msg.add(val);
            Udp.beginPacket(outIp, outPort);
            msg.send(Udp);
            Udp.endPacket();
            msg.empty();
        } else {
        // if statement checks that the value is not equal to the last value sent
        // if it is then the pot/value hasn't changed, so don't send another OSC message
        // this prevents OSC message flooding to Pure Data
          if (val != lastVal) {
            // Create a new OSC message under /test moniker
            // Add the integer value and perform UDP packet operations
            OSCMessage msg("/esp");
            msg.add(val);
            Udp.beginPacket(outIp, outPort);
            msg.send(Udp);
            Udp.endPacket();
            msg.empty();
          }
        }
        // Set the lastVal to current value for next loop cycle and reset the placeholder string
        lastVal = val;
        placeString = "";
      }
  }
}
